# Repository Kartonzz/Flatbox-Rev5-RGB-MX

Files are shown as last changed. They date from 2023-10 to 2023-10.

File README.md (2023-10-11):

# Flatbox-Rev5-RGB-MX
A simple Flatbox Rev5 fork with support for MX-style switches and addressable RGBLED's.

WARNING: Doesn't fit Choc v1/v2 enclosures. There will be a 5mm or higher gap between keycap corners and the enclosure if you try.

Original design by jfedor: 

https://github.com/jfedor2/flatbox/tree/master/hardware-rev5

Switch/LED footprints from marbastlib and keyswitches pretty:

https://github.com/ebastler/marbastlib
https://github.com/daprice/keyswitches.pretty

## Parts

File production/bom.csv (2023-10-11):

Designator | Footprint | Quantity | Value | LCSC Part #
C1, C10, C11, C12, C13, C14, C15, C16, C17, C18, C19, C2, C20, C21, C22, C23, C24, C25, C26, C27, C3, C4, C5, C6, C7, C8, C9 | 805 | 27 | 0.1uF | C138340
LED1, LED10, LED11, LED12, LED13, LED14, LED15, LED16, LED17, LED18, LED19, LED2, LED20, LED21, LED22, LED23, LED24, LED25, LED26, LED3, LED4, LED5, LED6, LED7, LED8, LED9 | LED_WS2812_2020 | 26 | WS2812_2020 | C965555
R1 | 805 | 1 | 470Ohm | C204522
R2 | 805 | 1 | 150kOhm | C114558
U1 | SOT-23-5 | 1 | SN74LV1T34DBV | C100024

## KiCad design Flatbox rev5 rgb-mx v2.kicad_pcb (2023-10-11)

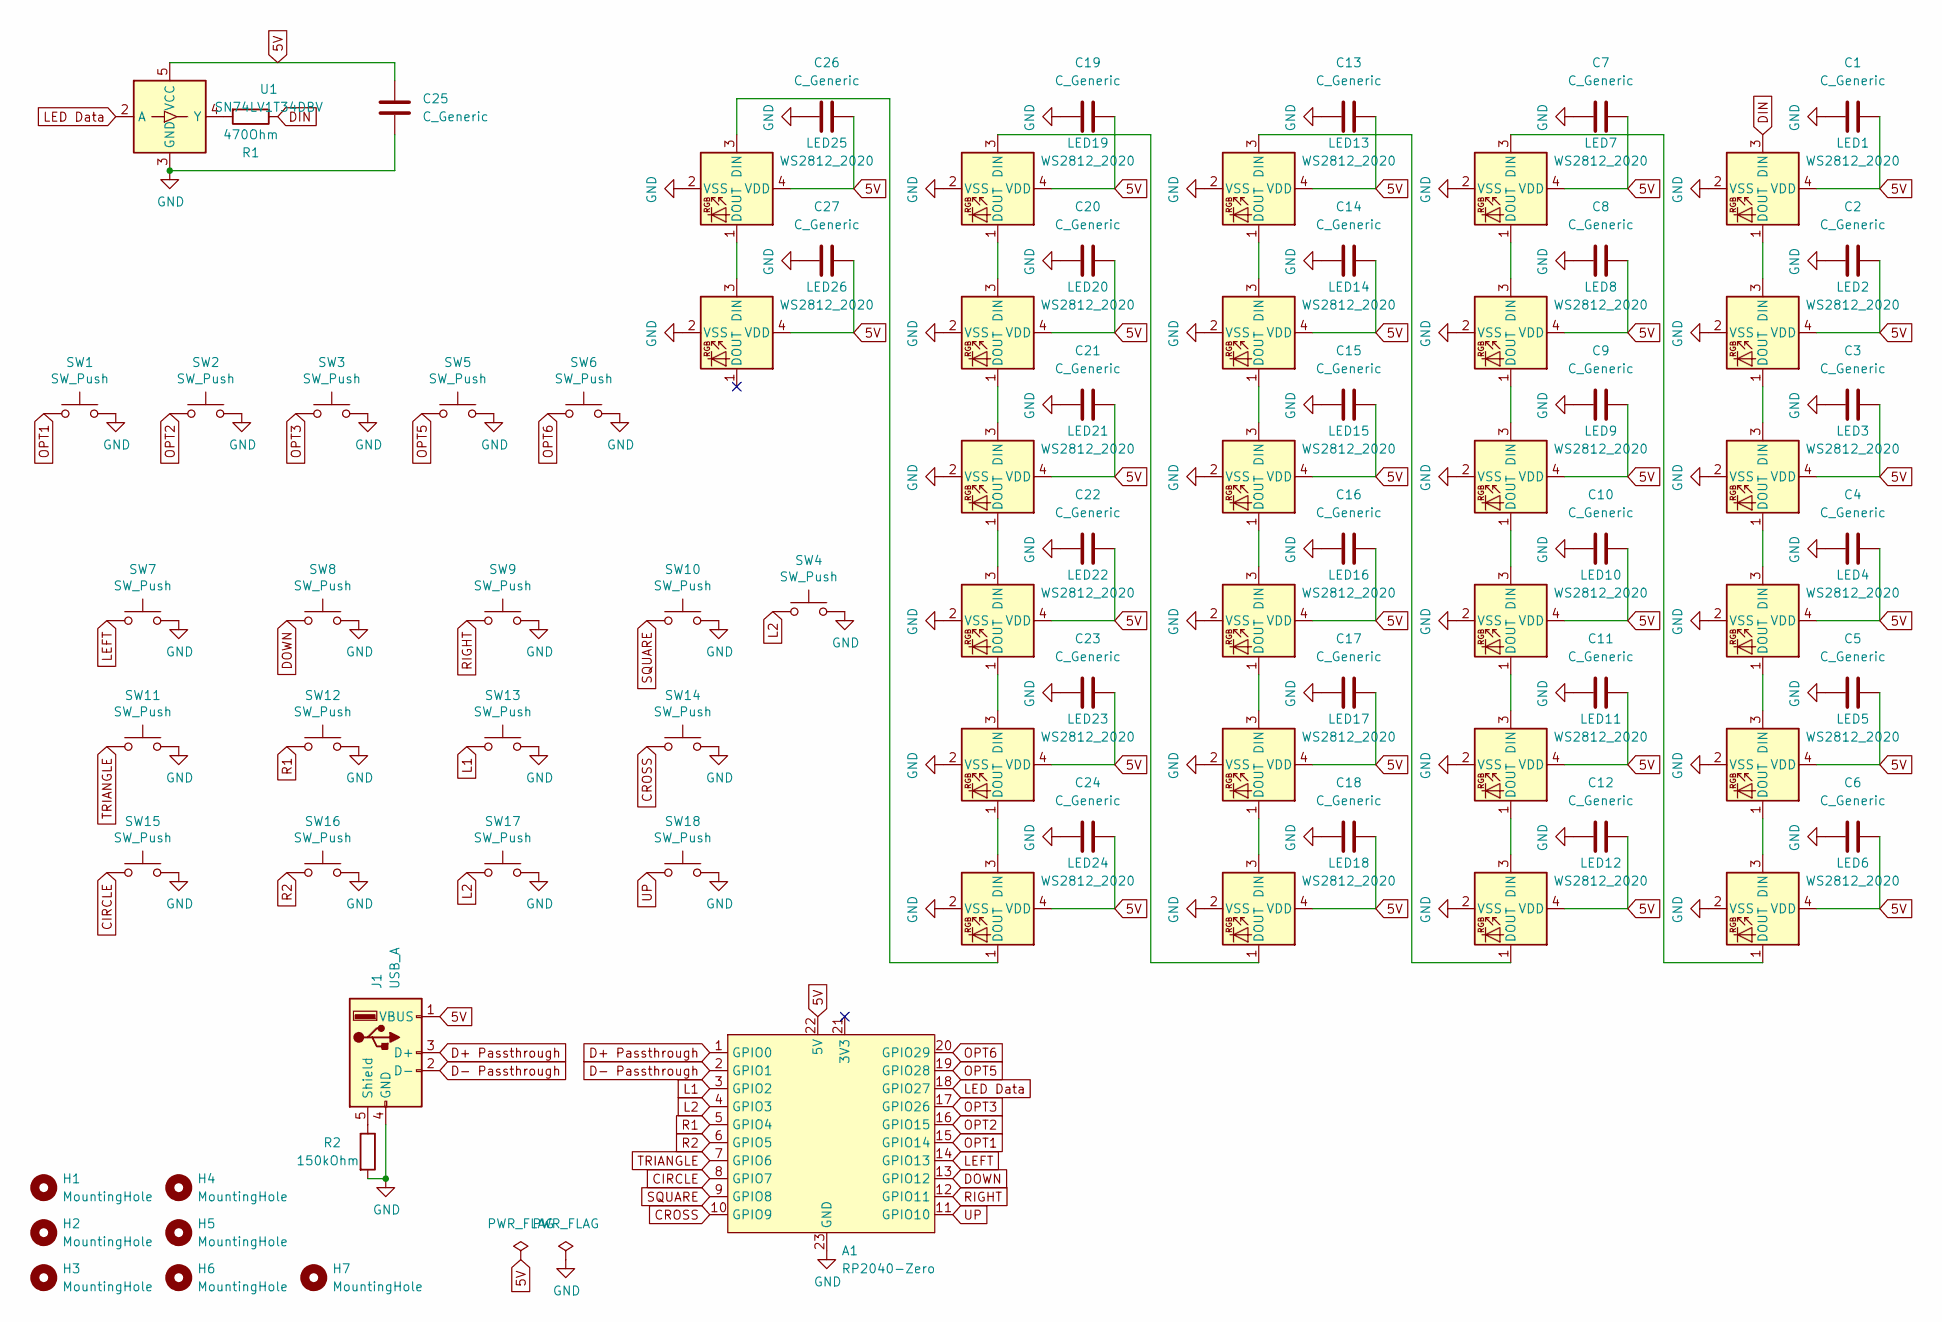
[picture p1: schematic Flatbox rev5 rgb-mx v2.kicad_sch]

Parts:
A1: RP2040-Zero
C1, C2, C3, C4, C5, C6, C7, C8, C9, C10, C11, C12, C13, C14, C15, C16, C17, C18, C19, C20, C21, C22, C23, C24, C25, C26, C27: C_Generic; C_0805_2012Metric
H1, H2, H3, H4, H5, H6, H7: MountingHole; MountingHole_6.4mm_M6
J1: USB_A; USB_A_CONNFLY_DS1095-WNR0
LED1, LED2, LED3, LED4, LED5, LED6, LED7, LED8, LED9, LED10, LED11, LED12, LED13, LED14, LED15, LED16, LED17, LED18, LED19, LED20, LED21, LED22, LED23, LED24, LED25, LED26: WS2812_2020; LED_WS2812_2020
R1: 470Ohm; R_0805_2012Metric
R2: 150kOhm; R_0805_2012Metric
SW1, SW2, SW3, SW5, SW6: SW_Push; SW_PUSH_6mm_H5mm
SW4, SW7, SW8, SW9, SW10, SW11, SW12, SW13, SW14, SW15, SW16, SW17, SW18: SW_Push; Kailh_socket_MX_optional
U1: SN74LV1T34DBV; SOT-23-5

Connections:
5V: A1.22 (5V), C1.1, C2.1, C3.1, C4.1, C5.1, C6.1, C7.1, C8.1, C9.1, C10.1, C11.1, C12.1, C13.1, C14.1, C15.1, C16.1, C17.1, C18.1, C19.1, C20.1, C21.1, C22.1, C23.1, C24.1, C25.1, C26.1, C27.1, J1.1 (VBUS), LED1.4 (VDD), LED2.4 (VDD), LED3.4 (VDD), LED4.4 (VDD), LED5.4 (VDD), LED6.4 (VDD), LED7.4 (VDD), LED8.4 (VDD), LED9.4 (VDD), LED10.4 (VDD), LED11.4 (VDD), LED12.4 (VDD), LED13.4 (VDD), LED14.4 (VDD), LED15.4 (VDD), LED16.4 (VDD), LED17.4 (VDD), LED18.4 (VDD), LED19.4 (VDD), LED20.4 (VDD), LED21.4 (VDD), LED22.4 (VDD), LED23.4 (VDD), LED24.4 (VDD), LED25.4 (VDD), LED26.4 (VDD), U1.5 (VCC)
CIRCLE: A1.8 (GPIO7), SW15.1
CROSS: A1.10 (GPIO9), SW14.1
D+ Passthrough: A1.1 (GPIO0), J1.3 (D+)
D- Passthrough: A1.2 (GPIO1), J1.2 (D-)
DIN: LED1.3 (DIN), R1.1
DOWN: A1.13 (GPIO12), SW8.1
GND: A1.23 (GND), C1.2, C2.2, C3.2, C4.2, C5.2, C6.2, C7.2, C8.2, C9.2, C10.2, C11.2, C12.2, C13.2, C14.2, C15.2, C16.2, C17.2, C18.2, C19.2, C20.2, C21.2, C22.2, C23.2, C24.2, C25.2, C26.2, C27.2, J1.4 (GND), LED1.2 (VSS), LED2.2 (VSS), LED3.2 (VSS), LED4.2 (VSS), LED5.2 (VSS), LED6.2 (VSS), LED7.2 (VSS), LED8.2 (VSS), LED9.2 (VSS), LED10.2 (VSS), LED11.2 (VSS), LED12.2 (VSS), LED13.2 (VSS), LED14.2 (VSS), LED15.2 (VSS), LED16.2 (VSS), LED17.2 (VSS), LED18.2 (VSS), LED19.2 (VSS), LED20.2 (VSS), LED21.2 (VSS), LED22.2 (VSS), LED23.2 (VSS), LED24.2 (VSS), LED25.2 (VSS), LED26.2 (VSS), R2.2, SW1.2, SW2.2, SW3.2, SW4.2, SW5.2, SW6.2, SW7.2, SW8.2, SW9.2, SW10.2, SW11.2, SW12.2, SW13.2, SW14.2, SW15.2, SW16.2, SW17.2, SW18.2, U1.3 (GND)
L1: A1.3 (GPIO2), SW13.1
L2: A1.4 (GPIO3), SW4.1, SW17.1
LED Data: A1.18 (GPIO27), U1.2 (A)
LEFT: A1.14 (GPIO13), SW7.1
unnamed: J1.5 (Shield), R2.1
unnamed: LED1.1 (DOUT), LED2.3 (DIN)
unnamed: LED2.1 (DOUT), LED3.3 (DIN)
unnamed: LED3.1 (DOUT), LED4.3 (DIN)
unnamed: LED4.1 (DOUT), LED5.3 (DIN)
unnamed: LED5.1 (DOUT), LED6.3 (DIN)
unnamed: LED6.1 (DOUT), LED7.3 (DIN)
unnamed: LED7.1 (DOUT), LED8.3 (DIN)
unnamed: LED8.1 (DOUT), LED9.3 (DIN)
unnamed: LED9.1 (DOUT), LED10.3 (DIN)
unnamed: LED10.1 (DOUT), LED11.3 (DIN)
unnamed: LED11.1 (DOUT), LED12.3 (DIN)
unnamed: LED12.1 (DOUT), LED13.3 (DIN)
unnamed: LED13.1 (DOUT), LED14.3 (DIN)
unnamed: LED14.1 (DOUT), LED15.3 (DIN)
unnamed: LED15.1 (DOUT), LED16.3 (DIN)
unnamed: LED16.1 (DOUT), LED17.3 (DIN)
unnamed: LED17.1 (DOUT), LED18.3 (DIN)
unnamed: LED18.1 (DOUT), LED19.3 (DIN)
unnamed: LED19.1 (DOUT), LED20.3 (DIN)
unnamed: LED20.1 (DOUT), LED21.3 (DIN)
unnamed: LED21.1 (DOUT), LED22.3 (DIN)
unnamed: LED22.1 (DOUT), LED23.3 (DIN)
unnamed: LED23.1 (DOUT), LED24.3 (DIN)
unnamed: LED24.1 (DOUT), LED25.3 (DIN)
unnamed: LED25.1 (DOUT), LED26.3 (DIN)
unnamed: R1.2, U1.4 (Y)
OPT1: A1.15 (GPIO14), SW1.1
OPT2: A1.16 (GPIO15), SW2.1
OPT3: A1.17 (GPIO26), SW3.1
OPT5: A1.19 (GPIO28), SW5.1
OPT6: A1.20 (GPIO29), SW6.1
R1: A1.5 (GPIO4), SW12.1
R2: A1.6 (GPIO5), SW16.1
RIGHT: A1.12 (GPIO11), SW9.1
SQUARE: A1.9 (GPIO8), SW10.1
TRIANGLE: A1.7 (GPIO6), SW11.1
UP: A1.11 (GPIO10), SW18.1

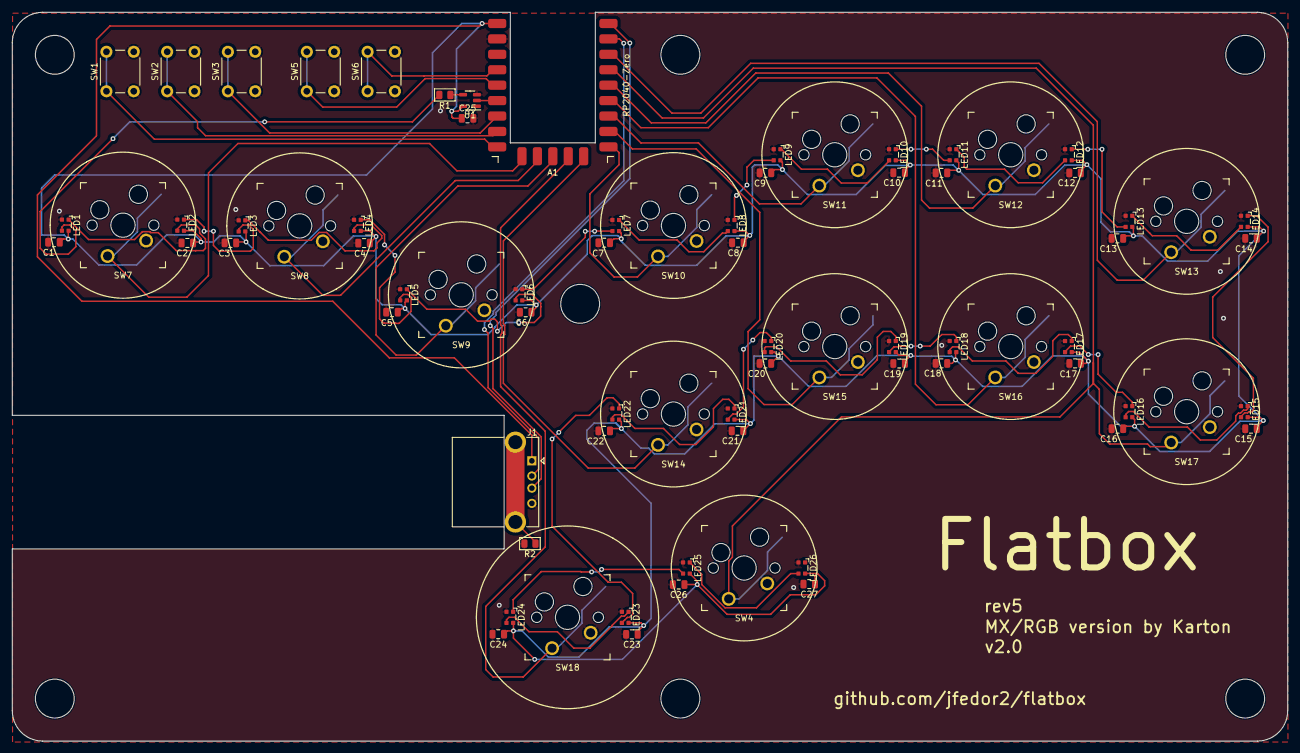
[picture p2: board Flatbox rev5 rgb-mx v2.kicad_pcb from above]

Board: 2 copper layers, 210.0 x 120.0 mm, 83 parts (0 on the bottom side), 50 nets.

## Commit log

2023-10-11 Add files via upload
    Production files for JLC.
    [bom.csv, designators.csv, positions.csv]
2023-10-11 Add files via upload
    Source files for kicad, 2 kicad footprint folders for things changed from other libraries
    [Flatbox rev5 rgb-mx v2.kicad_pcb, Flatbox rev5 rgb-mx v2.kicad_sch]
